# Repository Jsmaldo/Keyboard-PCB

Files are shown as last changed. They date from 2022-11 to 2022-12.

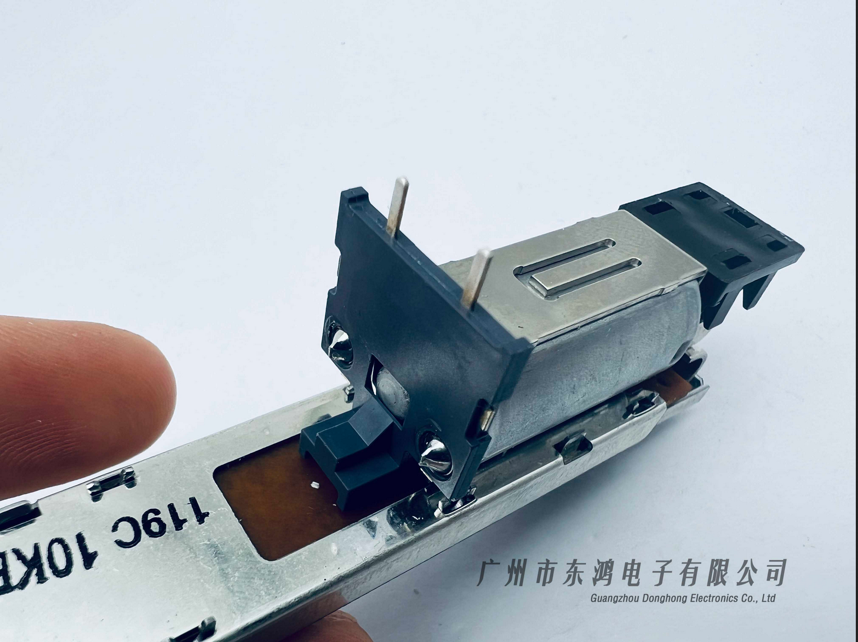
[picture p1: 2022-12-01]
Aliexpress slide pot/pic4.PNG

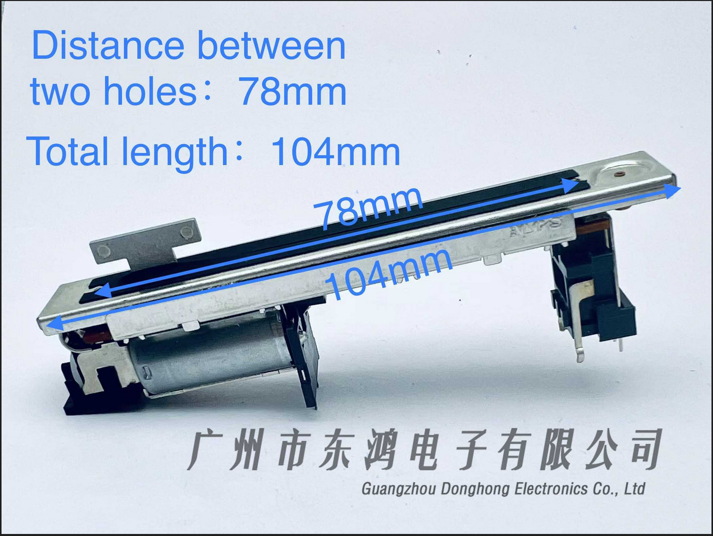
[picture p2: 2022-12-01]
Aliexpress slide pot/pic3.PNG

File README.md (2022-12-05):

# Keyboard-PCB
 Keyboard PCB Including F1-F24 & arduino with attached encoders & OLED screen


http://www.keyboard-layout-editor.com/#/gists/6a09a1fa51d7aa38f726f7da2f79e6d3

Special parts include:
 https://www.aliexpress.us/item/3256804572132735.html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
 https://www.digikey.com/en/products/detail/bourns-inc/PEC11L-4115F-S0020/4699168
 https://www.amazon.com/MakerFocus-Display-SSD1306-3-3V-5V-Arduino/dp/B079BN2J8V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

The OLED, slide pot, and rotary encoder will be controlled by a seperate processor, utilizing the deej project: https://github.com/omriharel/deej

Rotary encoder for selecting specific volume channel to adjust, and press-in to save slider value.
Motorized slide pot for adjusting specific channel volume
OLED for displaying current channel, and volume percentage.



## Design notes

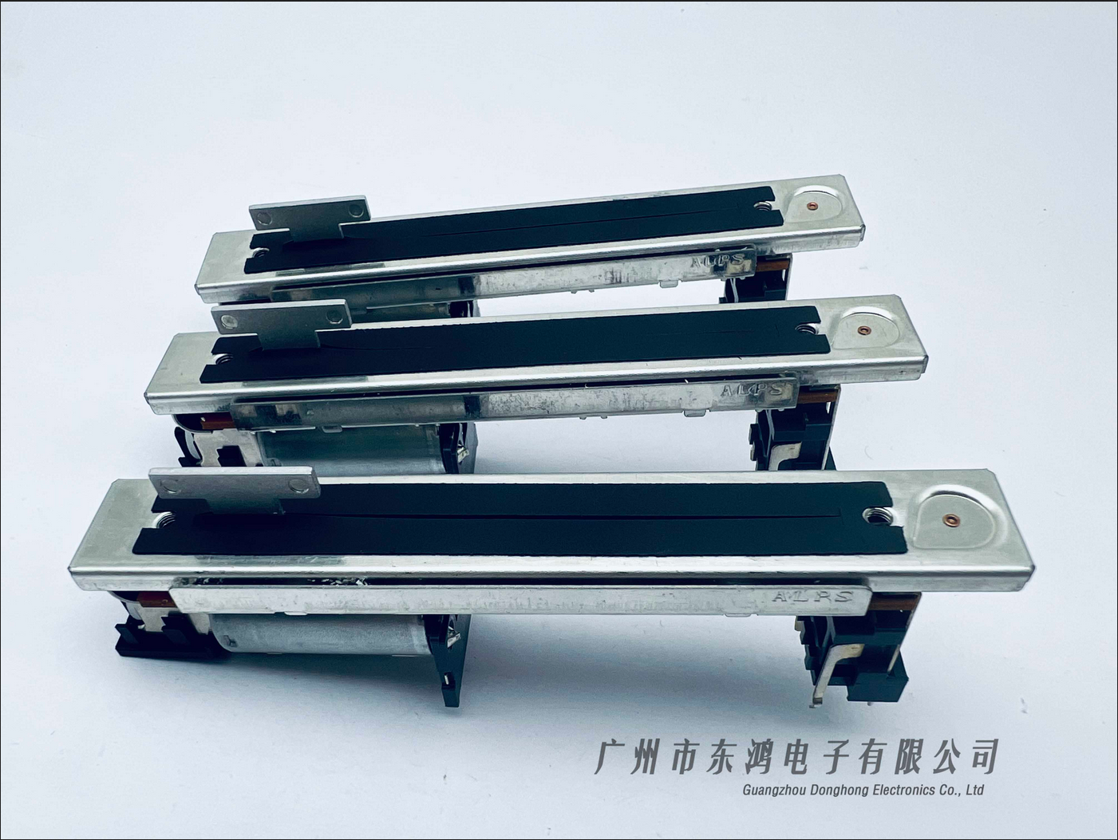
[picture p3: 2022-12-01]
Aliexpress slide pot/pic6.PNG

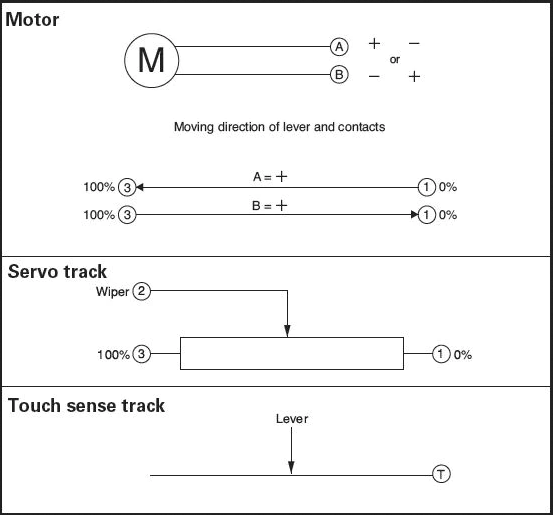
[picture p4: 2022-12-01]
Aliexpress slide pot/pic7.PNG

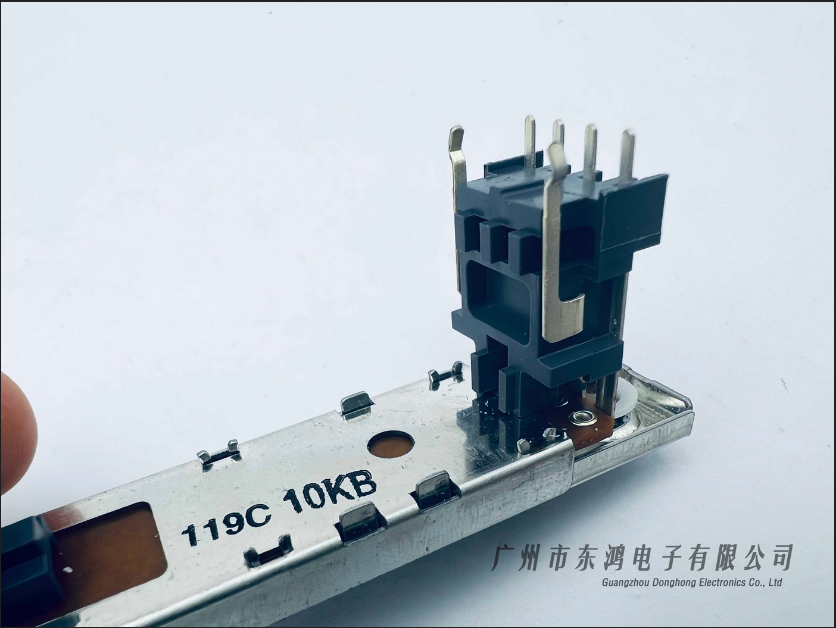
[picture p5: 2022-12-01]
Aliexpress slide pot/pic5.PNG

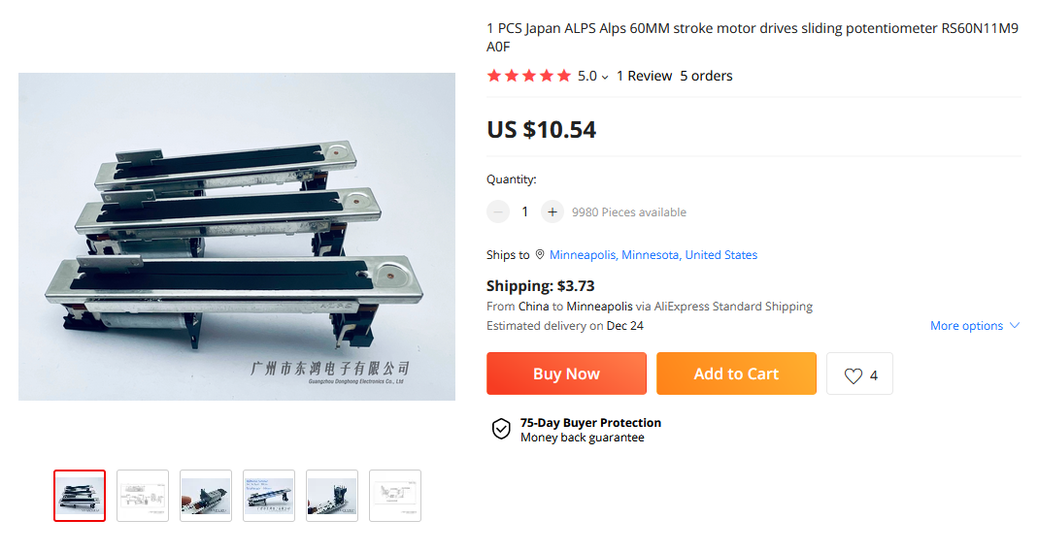
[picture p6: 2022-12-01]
Aliexpress slide pot/pic1.PNG

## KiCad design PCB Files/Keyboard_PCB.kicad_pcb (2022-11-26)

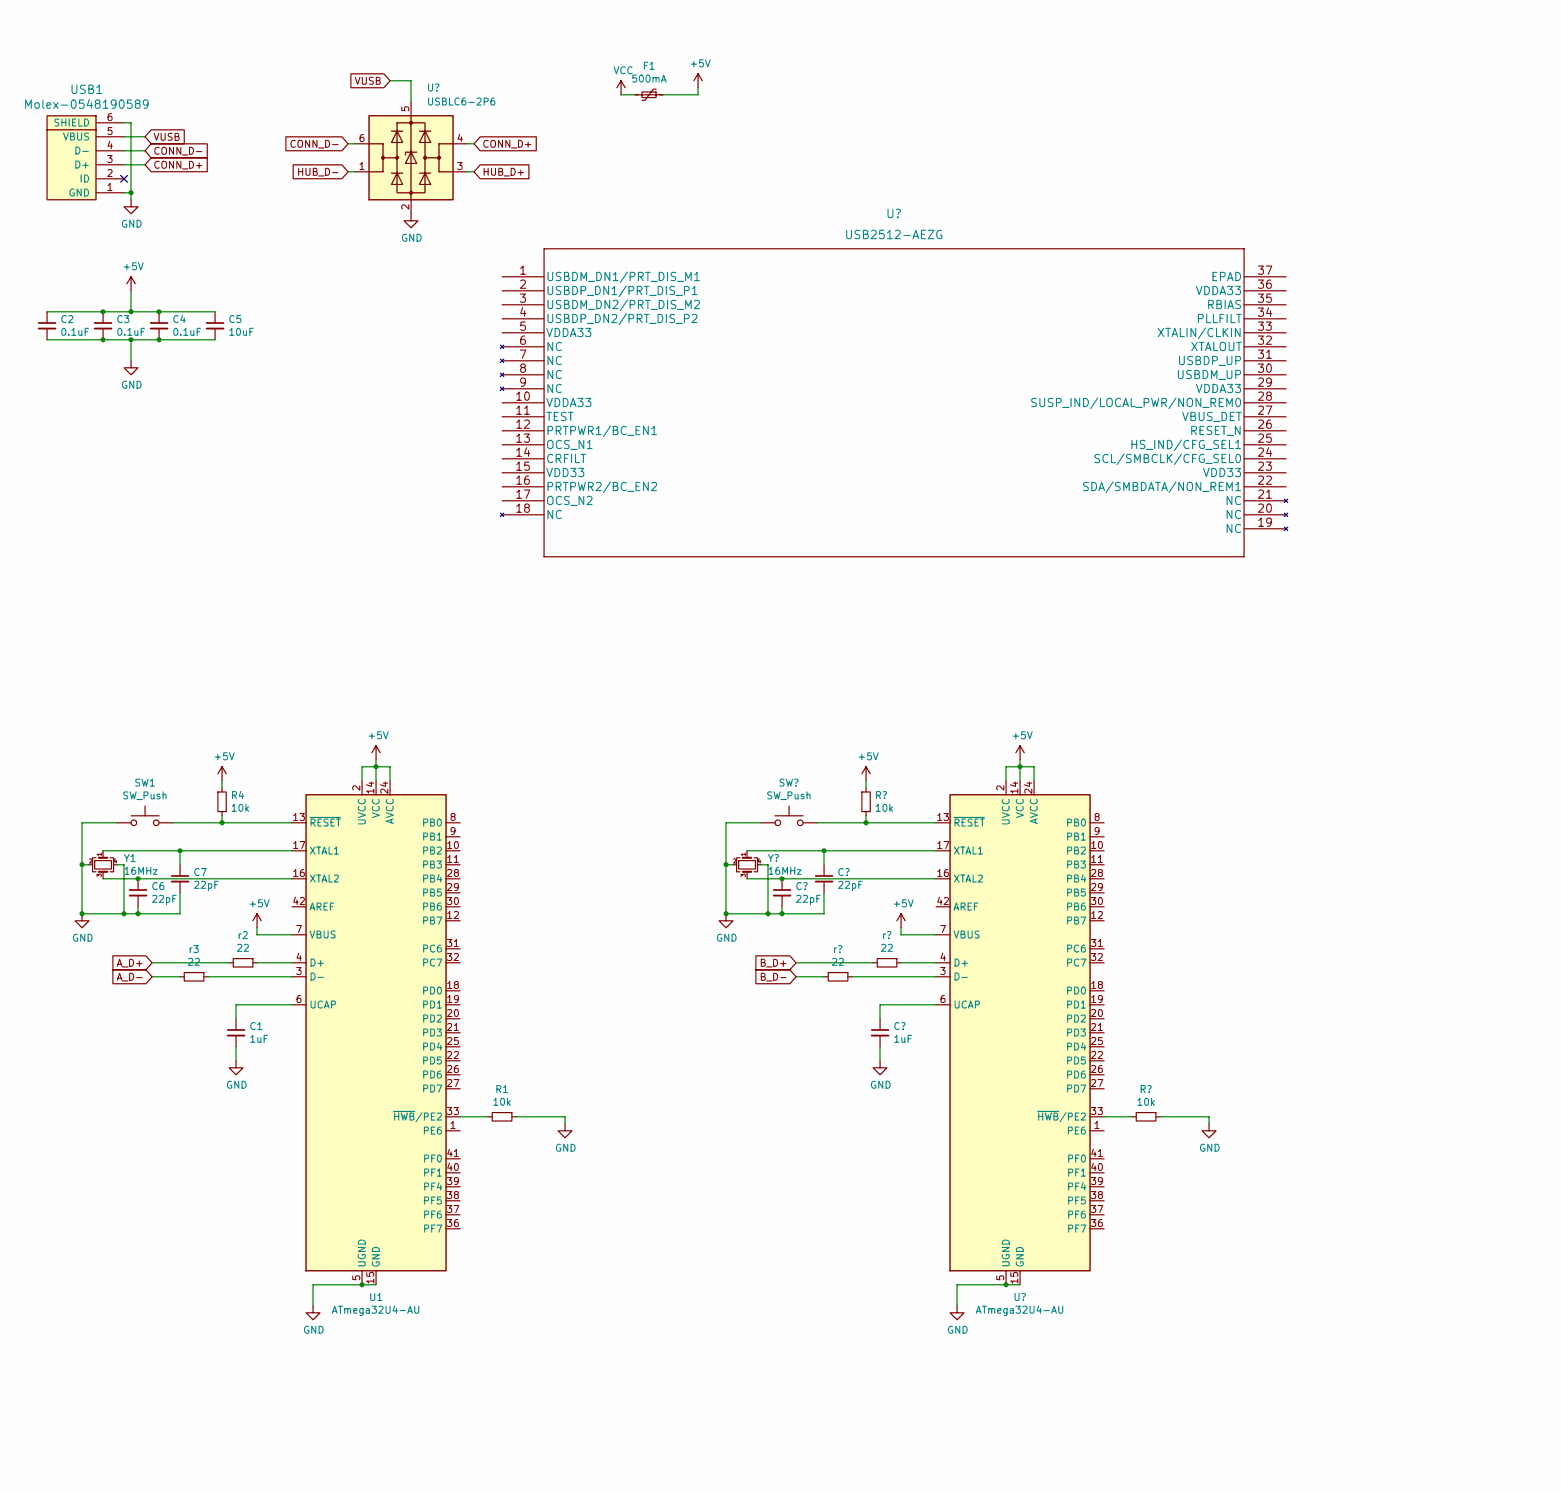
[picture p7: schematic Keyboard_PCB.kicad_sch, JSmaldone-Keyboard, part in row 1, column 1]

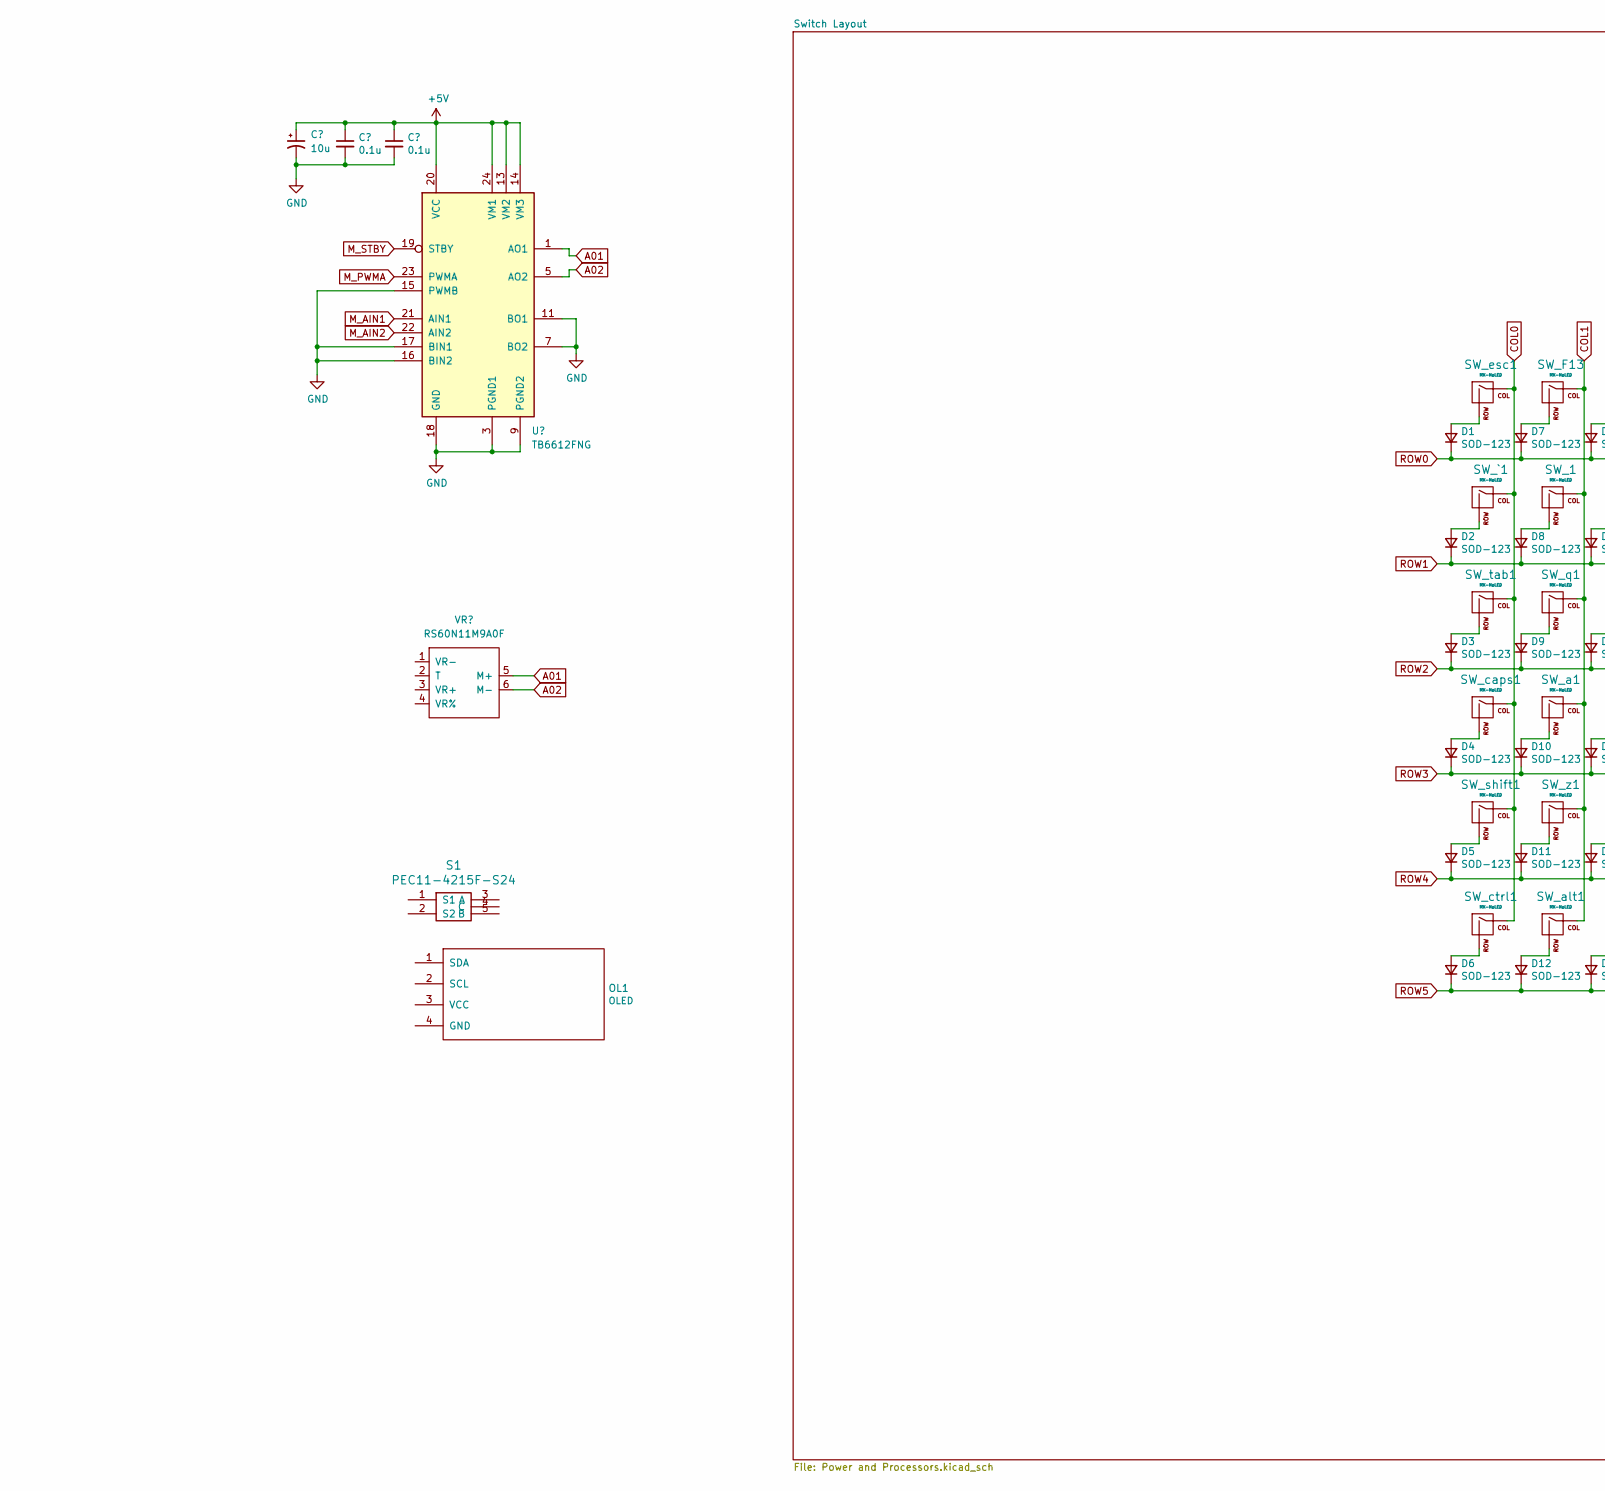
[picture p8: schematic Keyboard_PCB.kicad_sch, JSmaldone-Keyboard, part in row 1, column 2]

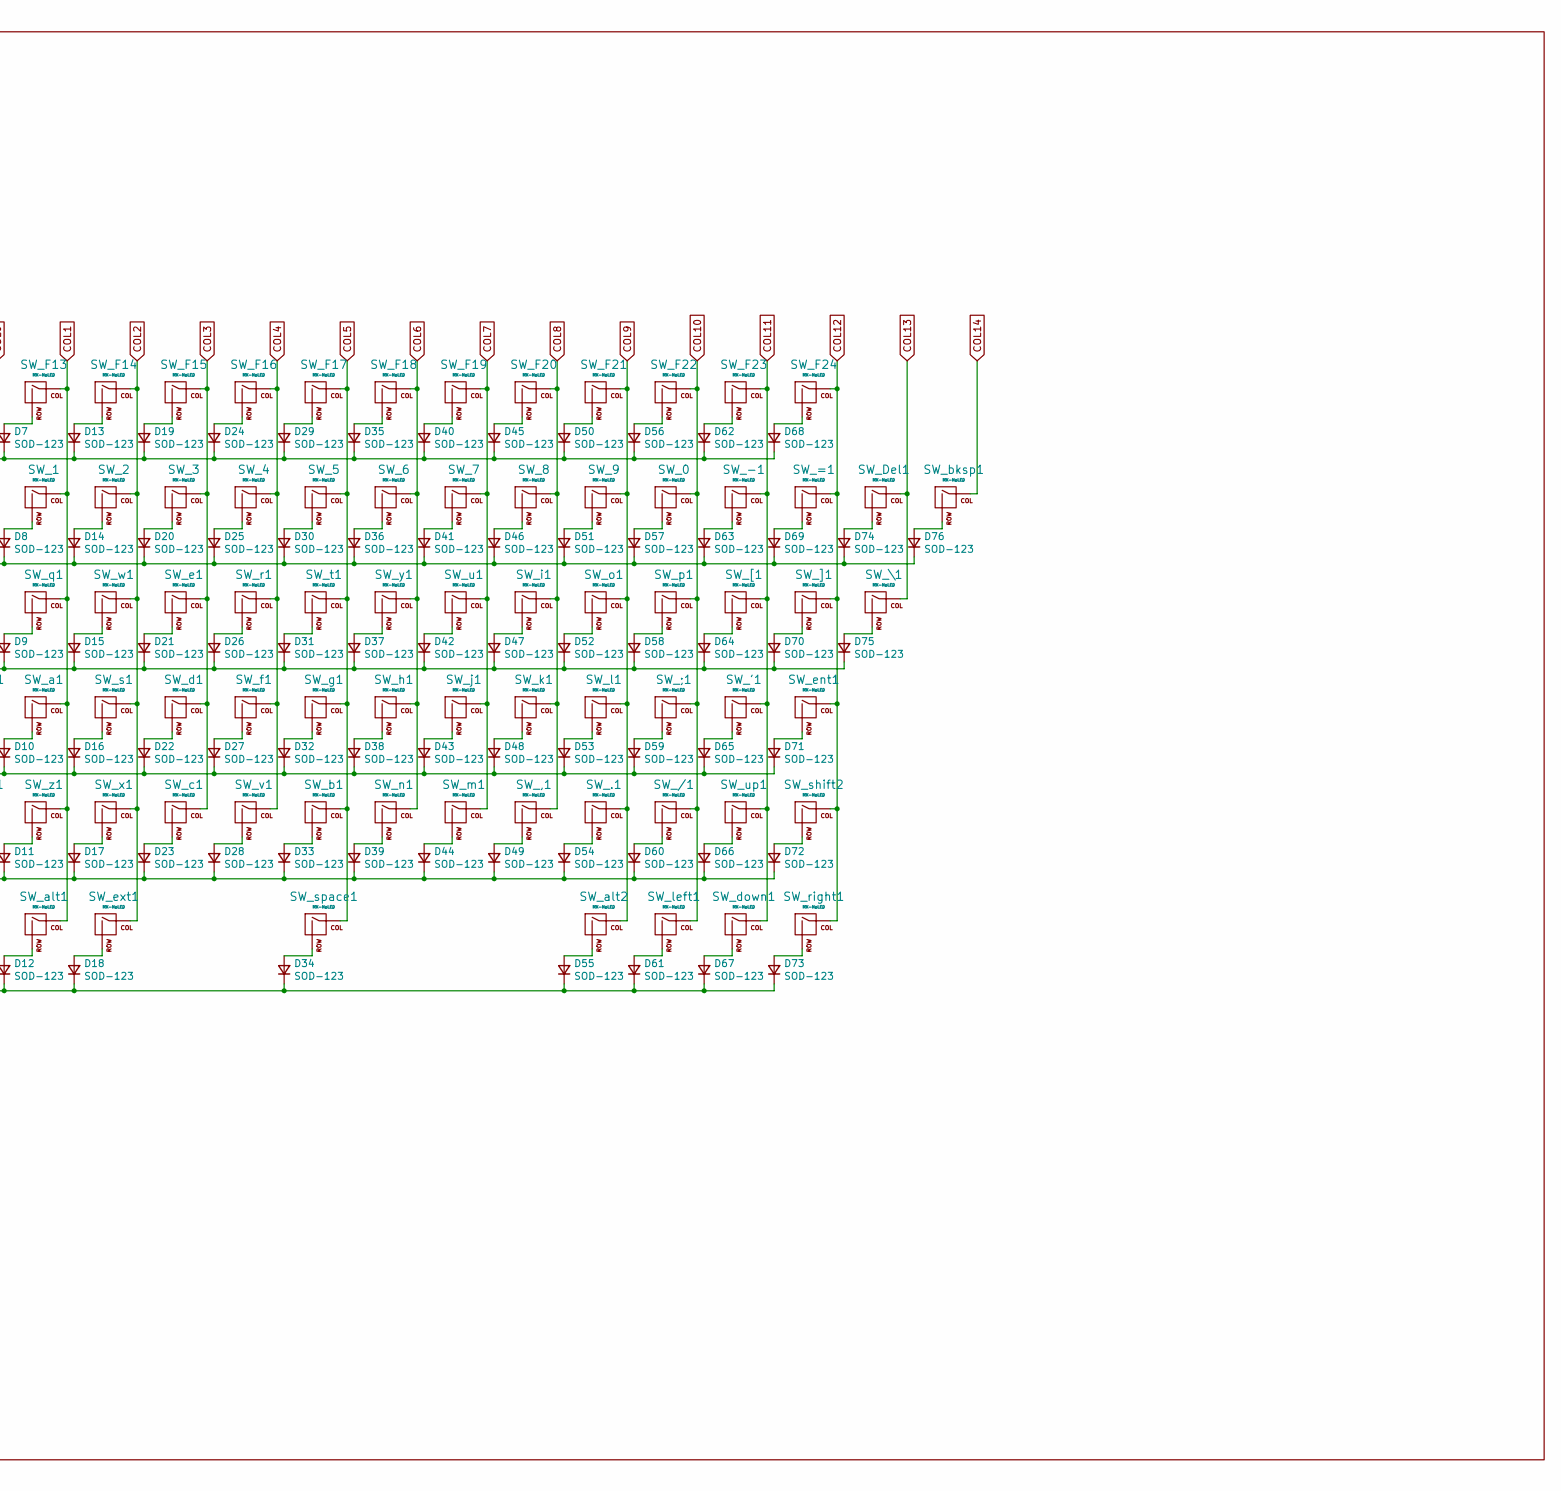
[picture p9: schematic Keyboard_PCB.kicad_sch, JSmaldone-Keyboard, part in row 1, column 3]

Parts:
C1: 1uF; C_0805_2012Metric
C2, C3, C4: 0.1uF; C_0805_2012Metric
C5: 10uF; C_0805_2012Metric
C6, C7: 22pF; C_0805_2012Metric
D1, D2, D3, D4, D5, D6, D7, D8, D9, D10, D11, D12, D13, D14, D15, D16, D17, D18, D19, D20, D21, D22, D23, D24, D25, D26, D27, D28, D29, D30, D31, D32, D33, D34, D35, D36, D37, D38, D39, D40, D41, D42, D43, D44, D45, D46, D47, D48, D49, D50, D51, D52, D53, D54, D55, D56, D57, D58, D59, D60, D61, D62, D63, D64, D65, D66, D67, D68, D69, D70, D71, D72, D73, D74, D75, D76: SOD-123; D_SOD-123
F1: 500mA; Fuse_1206_3216Metric
OL1: OLED; OLED_v2
R1, R4: 10k; R_0805_2012Metric
S1: PEC11-4215F-S24; PEC11R-4xxx-Sxxxx
SW1: SW_Push; SKQG-1155865
SW_0, SW_1, SW_2, SW_3, SW_4, SW_5, SW_6, SW_7, SW_8, SW_9, SW_.1: MX-NoLED; MX-1U-NoLED
SW_'1: MX-NoLED; MX-1U-NoLED
SW_,1: MX-NoLED; MX-1U-NoLED
SW_-1: MX-NoLED; MX-1U-NoLED
SW_/1: MX-NoLED; MX-1U-NoLED
SW_;1: MX-NoLED; MX-1U-NoLED
SW_=1: MX-NoLED; MX-1U-NoLED
SW_Del1: MX-NoLED; MX-1U-NoLED
SW_F13, SW_F14, SW_F15, SW_F16, SW_F17, SW_F18, SW_F19, SW_F20, SW_F21, SW_F22, SW_F23, SW_F24: MX-NoLED; MX-1U-NoLED
SW_[1: MX-NoLED; MX-1U-NoLED
SW_\1: MX-NoLED; MX-1.5U-NoLED
SW_]1: MX-NoLED; MX-1U-NoLED
SW_`1: MX-NoLED; MX-1U-NoLED
SW_a1: MX-NoLED; MX-1U-NoLED
SW_alt1, SW_alt2: MX-NoLED; MX-1U-NoLED
SW_b1: MX-NoLED; MX-1U-NoLED
SW_bksp1: MX-NoLED; MX-1U-NoLED
SW_c1: MX-NoLED; MX-1U-NoLED
SW_caps1: MX-NoLED; MX-1.75U-NoLED
SW_ctrl1: MX-NoLED; MX-1U-NoLED
SW_d1: MX-NoLED; MX-1U-NoLED
SW_down1: MX-NoLED; MX-1U-NoLED
SW_e1: MX-NoLED; MX-1U-NoLED
SW_ent1: MX-NoLED; MX-2.25U-NoLED
SW_esc1: MX-NoLED; MX-1U-NoLED
SW_ext1: MX-NoLED; MX-1U-NoLED
SW_f1: MX-NoLED; MX-1U-NoLED
SW_g1: MX-NoLED; MX-1U-NoLED
SW_h1: MX-NoLED; MX-1U-NoLED
SW_i1: MX-NoLED; MX-1U-NoLED
SW_j1: MX-NoLED; MX-1U-NoLED
SW_k1: MX-NoLED; MX-1U-NoLED
SW_l1: MX-NoLED; MX-1U-NoLED
SW_left1: MX-NoLED; MX-1U-NoLED
SW_m1: MX-NoLED; MX-1U-NoLED
SW_n1: MX-NoLED; MX-1U-NoLED
SW_o1: MX-NoLED; MX-1U-NoLED
SW_p1: MX-NoLED; MX-1U-NoLED
SW_q1: MX-NoLED; MX-1U-NoLED
SW_r1: MX-NoLED; MX-1U-NoLED
SW_right1: MX-NoLED; MX-1U-NoLED
SW_s1: MX-NoLED; MX-1U-NoLED
SW_shift1: MX-NoLED; MX-2.25U-NoLED
SW_shift2: MX-NoLED; MX-1.75U-NoLED
SW_space1: MX-NoLED; MX-7U-NoLED
SW_t1: MX-NoLED; MX-1U-NoLED
SW_tab1: MX-NoLED; MX-1.5U-NoLED
SW_u1: MX-NoLED; MX-1U-NoLED
SW_up1: MX-NoLED; MX-1U-NoLED
SW_v1: MX-NoLED; MX-1U-NoLED
SW_w1: MX-NoLED; MX-1U-NoLED
SW_x1: MX-NoLED; MX-1U-NoLED
SW_y1: MX-NoLED; MX-1U-NoLED
SW_z1: MX-NoLED; MX-1U-NoLED
U1: ATmega32U4-AU; TQFP-44_10x10mm_P0.8mm
USB1: Molex-0548190589
Y1: 16MHz; Crystal_SMD_3225-4Pin_3.2x2.5mm
r2, r3: 22; R_0805_2012Metric

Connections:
+5V: C2.1, C3.1, C4.1, C5.1, F1.1, R4.1, U1.2 (UVCC), U1.7 (VBUS), U1.14 (VCC), U1.24 (AVCC), U1.34 (VCC), U1.44 (AVCC)
COL0: SW_`1.1 (COL), SW_caps1.1 (COL), SW_ctrl1.1 (COL), SW_esc1.1 (COL), SW_shift1.1 (COL), SW_tab1.1 (COL)
COL1: SW_1.1 (COL), SW_F13.1 (COL), SW_a1.1 (COL), SW_alt1.1 (COL), SW_q1.1 (COL), SW_z1.1 (COL)
COL2: SW_2.1 (COL), SW_F14.1 (COL), SW_ext1.1 (COL), SW_s1.1 (COL), SW_w1.1 (COL), SW_x1.1 (COL)
COL3: SW_3.1 (COL), SW_F15.1 (COL), SW_c1.1 (COL), SW_d1.1 (COL), SW_e1.1 (COL)
COL4: SW_4.1 (COL), SW_F16.1 (COL), SW_f1.1 (COL), SW_r1.1 (COL), SW_v1.1 (COL)
COL5: SW_5.1 (COL), SW_F17.1 (COL), SW_b1.1 (COL), SW_g1.1 (COL), SW_space1.1 (COL), SW_t1.1 (COL)
COL6: SW_6.1 (COL), SW_F18.1 (COL), SW_h1.1 (COL), SW_n1.1 (COL), SW_y1.1 (COL)
COL7: SW_7.1 (COL), SW_F19.1 (COL), SW_j1.1 (COL), SW_m1.1 (COL), SW_u1.1 (COL)
COL8: SW_8.1 (COL), SW_,1.1 (COL), SW_F20.1 (COL), SW_i1.1 (COL), SW_k1.1 (COL)
COL9: SW_9.1 (COL), SW_.1.1 (COL), SW_F21.1 (COL), SW_alt2.1 (COL), SW_l1.1 (COL), SW_o1.1 (COL)
COL10: SW_0.1 (COL), SW_/1.1 (COL), SW_;1.1 (COL), SW_F22.1 (COL), SW_left1.1 (COL), SW_p1.1 (COL)
COL11: SW_'1.1 (COL), SW_-1.1 (COL), SW_F23.1 (COL), SW_[1.1 (COL), SW_down1.1 (COL), SW_up1.1 (COL)
COL12: SW_=1.1 (COL), SW_F24.1 (COL), SW_]1.1 (COL), SW_ent1.1 (COL), SW_right1.1 (COL), SW_shift2.1 (COL)
COL13: SW_Del1.1 (COL), SW_\1.1 (COL)
COL14: SW_bksp1.1 (COL)
GND: C1.2, C2.2, C3.2, C4.2, C5.2, C6.2, C7.2, R1.1, SW1.1, U1.5 (UGND), U1.15 (GND), U1.23 (GND), U1.35 (GND), U1.43 (GND), USB1.1 (GND), USB1.6 (SHIELD), Y1.2, Y1.4
unnamed: C1.1, U1.6 (UCAP)
unnamed: C6.1, U1.16 (XTAL2), Y1.3
unnamed: C7.1, U1.17 (XTAL1), Y1.1
unnamed: D1.2 (A), SW_esc1.2 (ROW)
unnamed: D2.2 (A), SW_`1.2 (ROW)
unnamed: D3.2 (A), SW_tab1.2 (ROW)
unnamed: D4.2 (A), SW_caps1.2 (ROW)
unnamed: D5.2 (A), SW_shift1.2 (ROW)
unnamed: D6.2 (A), SW_ctrl1.2 (ROW)
unnamed: D7.2 (A), SW_F13.2 (ROW)
unnamed: D8.2 (A), SW_1.2 (ROW)
unnamed: D9.2 (A), SW_q1.2 (ROW)
unnamed: D10.2 (A), SW_a1.2 (ROW)
unnamed: D11.2 (A), SW_z1.2 (ROW)
unnamed: D12.2 (A), SW_alt1.2 (ROW)
unnamed: D13.2 (A), SW_F14.2 (ROW)
unnamed: D14.2 (A), SW_2.2 (ROW)
unnamed: D15.2 (A), SW_w1.2 (ROW)
unnamed: D16.2 (A), SW_s1.2 (ROW)
unnamed: D17.2 (A), SW_x1.2 (ROW)
unnamed: D18.2 (A), SW_ext1.2 (ROW)
unnamed: D19.2 (A), SW_F15.2 (ROW)
unnamed: D20.2 (A), SW_3.2 (ROW)
unnamed: D21.2 (A), SW_e1.2 (ROW)
unnamed: D22.2 (A), SW_d1.2 (ROW)
unnamed: D23.2 (A), SW_c1.2 (ROW)
unnamed: D24.2 (A), SW_F16.2 (ROW)
unnamed: D25.2 (A), SW_4.2 (ROW)
unnamed: D26.2 (A), SW_r1.2 (ROW)
unnamed: D27.2 (A), SW_f1.2 (ROW)
unnamed: D28.2 (A), SW_v1.2 (ROW)
unnamed: D29.2 (A), SW_F17.2 (ROW)
unnamed: D30.2 (A), SW_5.2 (ROW)
unnamed: D31.2 (A), SW_t1.2 (ROW)
unnamed: D32.2 (A), SW_g1.2 (ROW)
unnamed: D33.2 (A), SW_b1.2 (ROW)
unnamed: D34.2 (A), SW_space1.2 (ROW)
unnamed: D35.2 (A), SW_F18.2 (ROW)
unnamed: D36.2 (A), SW_6.2 (ROW)
unnamed: D37.2 (A), SW_y1.2 (ROW)
unnamed: D38.2 (A), SW_h1.2 (ROW)
unnamed: D39.2 (A), SW_n1.2 (ROW)
unnamed: D40.2 (A), SW_F19.2 (ROW)
unnamed: D41.2 (A), SW_7.2 (ROW)
unnamed: D42.2 (A), SW_u1.2 (ROW)
unnamed: D43.2 (A), SW_j1.2 (ROW)
unnamed: D44.2 (A), SW_m1.2 (ROW)
unnamed: D45.2 (A), SW_F20.2 (ROW)
unnamed: D46.2 (A), SW_8.2 (ROW)
unnamed: D47.2 (A), SW_i1.2 (ROW)
unnamed: D48.2 (A), SW_k1.2 (ROW)
unnamed: D49.2 (A), SW_,1.2 (ROW)
unnamed: D50.2 (A), SW_F21.2 (ROW)
unnamed: D51.2 (A), SW_9.2 (ROW)
unnamed: D52.2 (A), SW_o1.2 (ROW)
unnamed: D53.2 (A), SW_l1.2 (ROW)
unnamed: D54.2 (A), SW_.1.2 (ROW)
unnamed: D55.2 (A), SW_alt2.2 (ROW)
unnamed: D56.2 (A), SW_F22.2 (ROW)
unnamed: D57.2 (A), SW_0.2 (ROW)
unnamed: D58.2 (A), SW_p1.2 (ROW)
unnamed: D59.2 (A), SW_;1.2 (ROW)
unnamed: D60.2 (A), SW_/1.2 (ROW)
unnamed: D61.2 (A), SW_left1.2 (ROW)
unnamed: D62.2 (A), SW_F23.2 (ROW)
unnamed: D63.2 (A), SW_-1.2 (ROW)
unnamed: D64.2 (A), SW_[1.2 (ROW)
unnamed: D65.2 (A), SW_'1.2 (ROW)
unnamed: D66.2 (A), SW_up1.2 (ROW)
unnamed: D67.2 (A), SW_down1.2 (ROW)
unnamed: D68.2 (A), SW_F24.2 (ROW)
unnamed: D69.2 (A), SW_=1.2 (ROW)
unnamed: D70.2 (A), SW_]1.2 (ROW)
unnamed: D71.2 (A), SW_ent1.2 (ROW)
unnamed: D72.2 (A), SW_shift2.2 (ROW)
unnamed: D73.2 (A), SW_right1.2 (ROW)
unnamed: D74.2 (A), SW_Del1.2 (ROW)
unnamed: D75.2 (A), SW_\1.2 (ROW)
unnamed: D76.2 (A), SW_bksp1.2 (ROW)
unnamed: R1.2, U1.33 (~HWB/PE2)
unnamed: R4.2, SW1.2, U1.13 (~RESET)
unnamed: U1.3 (D-), r3.1
unnamed: U1.4 (D+), r2.1
ROW0: D1.1 (K), D7.1 (K), D13.1 (K), D19.1 (K), D24.1 (K), D29.1 (K), D35.1 (K), D40.1 (K), D45.1 (K), D50.1 (K), D56.1 (K), D62.1 (K), D68.1 (K)
ROW1: D2.1 (K), D8.1 (K), D14.1 (K), D20.1 (K), D25.1 (K), D30.1 (K), D36.1 (K), D41.1 (K), D46.1 (K), D51.1 (K), D57.1 (K), D63.1 (K), D69.1 (K), D74.1 (K), D76.1 (K)
ROW2: D3.1 (K), D9.1 (K), D15.1 (K), D21.1 (K), D26.1 (K), D31.1 (K), D37.1 (K), D42.1 (K), D47.1 (K), D52.1 (K), D58.1 (K), D64.1 (K), D70.1 (K), D75.1 (K)
ROW3: D4.1 (K), D10.1 (K), D16.1 (K), D22.1 (K), D27.1 (K), D32.1 (K), D38.1 (K), D43.1 (K), D48.1 (K), D53.1 (K), D59.1 (K), D65.1 (K), D71.1 (K)
ROW4: D5.1 (K), D11.1 (K), D17.1 (K), D23.1 (K), D28.1 (K), D33.1 (K), D39.1 (K), D44.1 (K), D49.1 (K), D54.1 (K), D60.1 (K), D66.1 (K), D72.1 (K)
ROW5: D6.1 (K), D12.1 (K), D18.1 (K), D34.1 (K), D55.1 (K), D61.1 (K), D67.1 (K), D73.1 (K)

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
Board: 2 copper layers, 171 parts (92 on the bottom side), 108 nets, no tracks yet.

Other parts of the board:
R2: PSM60-081A-103B2

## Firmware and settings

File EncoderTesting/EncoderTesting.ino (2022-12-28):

#include <config.h>
#include <SPI.h>
#include <Wire.h>
#include <Adafruit_GFX.h>
#include <Adafruit_SSD1306.h>

unsigned long screenTimeMillis = 0; // monitor screen active time
unsigned long screenUpdateMillis; // only write to the screen at a set rate
bool screenIdle;

bool increase, lastIncrease, deb_increase;
bool decrease, lastDecrease, deb_decrease;
bool press, lastPress, deb_press;

bool _A, _B;
bool last_A;

unsigned long rotateDebounce;
unsigned long pressDebounce;

int slideValue, lastSlideValue;
int volume, lastVolume; 

int channel, lastChannel;

String channels[] ={ //Setup user defined channel names, refer to deej config.yaml file.
  "MAIN",
  "MIC",
  "DISCORD",
  "FIREFOX",
  "GAME",
  "SYSTEM",
  "MUSIC"
};
int channelVolumes[6];

void setup() {
  if(!display.begin(SSD1306_SWITCHCAPVCC, SCREEN_ADDRESS)) { //initalize display
    Serial.println(F("SSD1306 allocation failed"));
    for(;;); 
  }
  display.clearDisplay();
  display.setRotation(0);  
  display.setTextSize(2);
  display.setTextColor(SSD1306_WHITE, SSD1306_BLACK);

  //initialize input/output pins
  pinMode(rotary_press, INPUT_PULLUP);
  pinMode(rotary_A, INPUT_PULLUP);
  pinMode(rotary_B, INPUT_PULLUP);
  pinMode(slider, INPUT);
  pinMode(pwmA, OUTPUT); pinMode(in1A, OUTPUT); pinMode(in2A, OUTPUT);
}
void loop() {
  DigitalInputMonitoring();
  AnalogInputMonitoring();
  ScreenUpdates();
}
void ScreenUpdates(){
  if(millis() - screenTimeMillis < 5000){
    if(millis() - screenUpdateMillis > 250){
      display.clearDisplay();
      display.setCursor(10, 0);
      display.println(channels[channel]);
      display.setCursor(10,18);
      display.println((channelVolumes[channel]) + String("%"));
      display.display();
      screenIdle = 0;
      lastChannel = channel;
    }
  }
  else{
    display.clearDisplay();
    display.display();
    screenIdle = 1;
  }
}
void DigitalInputMonitoring(){
  _A = digitalRead(rotary_A);
  _B = digitalRead(rotary_B);
  press = digitalRead(rotary_press);

  if(_A != last_A && _A == 0){
    if(millis() - rotateDebounce >= 150){
      if(_B != _A){
        screenTimeMillis = millis();
        if(screenIdle == 0) channel--;
        if(channel <= -1) channel = 6;
        return;
      }
      else{
        screenTimeMillis = millis();
        if(screenIdle == 0) channel++;
        if(channel > 6) channel = 0;
        return;
      }
    }
  }
  last_A = _A;

  if((press != lastPress) && (digitalRead(rotary_press) == 0)){
    if(millis() - pressDebounce > 100){
      screenTimeMillis = millis();
      pressDebounce = millis();
      deb_press = 1;
      return;
    }
    else{
      deb_press = 0;
    }
  }

  lastIncrease = increase;
  lastDecrease = decrease;
  lastPress = press;
}
void AnalogInputMonitoring(){
  slideValue = analogRead(slider); //read pot voltage
  channelVolumes[channel] = map(slideValue, 0, 1024, 100, 0);
  if(channelVolumes[channel] != lastVolume){
    screenTimeMillis = millis();
  }
  lastVolume = channelVolumes[channel];
}

void driveMotorUP(){
  if(digitalRead(touch == 0)){
    digitalWrite(in1A, HIGH);
    digitalWrite(in2A, LOW);
    analogWrite(pwmA, 255);
  }
  else{
    digitalWrite(in1A, LOW);
    digitalWrite(in2A, LOW);
    analogWrite(pwmA, 0);
  }
}

void driveMotorDOWN(){
  if(digitalRead(touch == 0)){
    digitalWrite(in1A, LOW);
    digitalWrite(in2A, HIGH);
    analogWrite(pwmA, 255);
  }
  else{
    digitalWrite(in1A, LOW);
    digitalWrite(in2A, LOW);
    analogWrite(pwmA, 0);
  }
}

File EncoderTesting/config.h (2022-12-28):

#define SCREEN_WIDTH 128 // OLED display width, in pixels
#define SCREEN_HEIGHT 32 // OLED display height, in pixels
#define OLED_RESET     4 // Reset pin # (or -1 if sharing Arduino reset pin)
#define SCREEN_ADDRESS 0x3C ///< See datasheet for Address; 0x3D for 128x64, 0x3C for 128x32
Adafruit_SSD1306 display(SCREEN_WIDTH, SCREEN_HEIGHT, &Wire, OLED_RESET);

#define rotary_press 14 //rotary encoder press input
#define rotary_A 6 //rotary encoder A channel
#define rotary_B 5 //rotary encoder B channel

#define slider A3 //slider analog input
#define touch A2 //slider capacitive touch input

//use pins for TB6612FNG motor driver
#define pwmA 3 //driver PWM Channel
#define in1A 2 //driver CW Channel
#define in2A 4 //driver CCW Channel

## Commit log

2022-11-21 New blank project
    [Keyboard_PCB.kicad_pcb, Keyboard_PCB.sch]
2022-11-21 Schematic sample populated
2022-11-21 PCB update
    some progress on pcb
    [Keyboard_PCB.kicad_pcb]
2022-11-25 keyboard laid out in schematic
    [Keyboard_PCB.sch]
2022-11-25 link deej project
    [dimitar-schematic.sch]
2022-11-26 updated PCB
    [Keyboard_PCB.kicad_pcb, Keyboard_PCB.sch]
2022-11-26 added parts
    added OLED, Slidepot, and Rotary encoder to sch and pcb
    [Keyboard_PCB.kicad_pcb, Keyboard_PCB.sch]
2022-12-01 test rotary encoder with OLED
    testing rotary encoder and OLED circuit
2022-12-03 cleaning up folders
    [Keyboard_PCB.kicad_pcb, Keyboard_PCB.sch, dimitar-schematic.sch]
2022-12-05 folder & code updates
    putting pcb files in a new folder broke some library paths. Working on incorporating analog slider.
    [Keyboard_PCB.sch]
2022-12-29 adding components
    [Keyboard_PCB.kicad_sch, Power and Processors.kicad_sch]
2023-01-03 Schematic Organization
    -separated schematic into stages / sections
    [Keyboard.kicad_sch, Keyboard_PCB.kicad_sch, V_slider.kicad_sch]
2023-02-23 updated PCB layout
    assigned col/row pins and organized keys according to keymap

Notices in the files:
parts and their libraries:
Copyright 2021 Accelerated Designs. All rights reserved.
